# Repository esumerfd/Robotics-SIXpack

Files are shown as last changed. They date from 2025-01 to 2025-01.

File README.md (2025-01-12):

# Robotics-SIXpack

A free Robotics hexapod by delta3robotics. 

* https://wonderl.ink/@delta3robotics
* https://cults3d.com/de/modell-3d/verschiedene/sixpack

Chris wrote all the original code and hosts a Discord to help people learn about robotics.

* https://discord.com/invite/fj6HPAsYT8

I am a novice in robotics so these are just my experiments built on top of Chris's work.

My goal is to add a build and upload solution that doesn't use the Arduino IDE. So, a 
simple `make` solution using the arduino-cli to build and upload.

# Install - Mac only.

* brew install arduino-cli
* USB to Serial
    * Macs older than Maverics need these drivers, but new are good to go.
        * Install FTDI drivers: https://ftdichip.com
* make init

# Build

The build step installs the packages and runs the arduino-cli compile to generate the image

* make build

# Upload

You will have to work out the serial port to upload to. Once you have plugged it in, you should see it in this list

* make usb

Then you can upload the built solution:

* SERIAL_PORT=/dev/cu.usbserial-OR-SOMETHING make upload

# Debugging

Trying to create an independent module that can be used to verify the hardware is functioning as expected. A website contains options to testing each component.

* make PROJECT=Firmware/SIXpackDebug build

# References

RS-232 comms. The communication between the computer and the esp32-cam requires a usb to serial connection that is achieved with a device driver and a chip of some kind. A common solution is the FTDI FT232RL chip mounted on a board. You can get a couple from Amazon:

* [Amazon FTDI component](https://www.amazon.com/gp/product/B07WYLK437)

If you are interested in the backround of RS-232 and how it works at the link level this is a good article.

* [MacOS Big Sur & RS-232 Serial Communications](https://just.graphica.com.au/tips/macos-big-sur-rs232/)

Ultimatly you don't need any additional serial drivers since Mac OSX includes its own in versions 11 onwards. I am testing on Serquoia 15 and it works.

Optional alternative USB -> Serial driver:

* [Prolific PL2303GT](https://www.prolific.com.tw/us/ShowProduct.aspx?pcid=41&showlevel=0017-0037-0041)
* [Aideepen USB to TTL RS232 3.3V Serial Download Cable Adapter Original 6PIN 5V FTDI-232 Module 1M Wire AVR ARM(Combined Head)](https://www.amazon.com/gp/product/B07FVMCPMT)
* [HiLetgo 5pcs USB to Serial USB to TTL CH340 Module with STC Microcontroller Download Adapter](amazon.com/gp/product/B00LZV1G6K)
* [PL2303GT USB to RS232 Serial Cable - UART Upgrade Download Module for RS232 Level (Non-TTL)](https://www.amazon.com/dp/B0D3CFX4PC)

## Mac FTDI Story

When I first started this project everything work, the ftdi drivers installed and everything worked. Then I got a new mac i9 chip, running OSX 15, and nothing worted anymore.

In the old days, and based on Chris's instructions, an FDTI chip set is required to connect to the esp32cam board. 

Today, the FTDI board, has build in support in Mac OSX for this board.

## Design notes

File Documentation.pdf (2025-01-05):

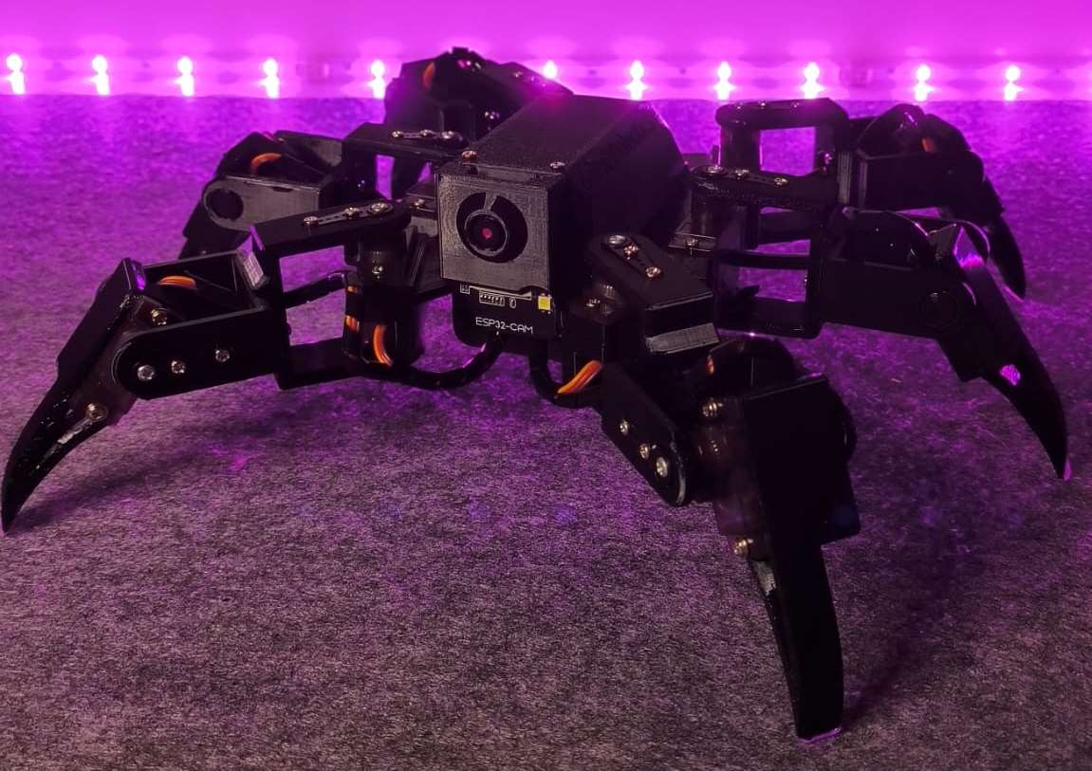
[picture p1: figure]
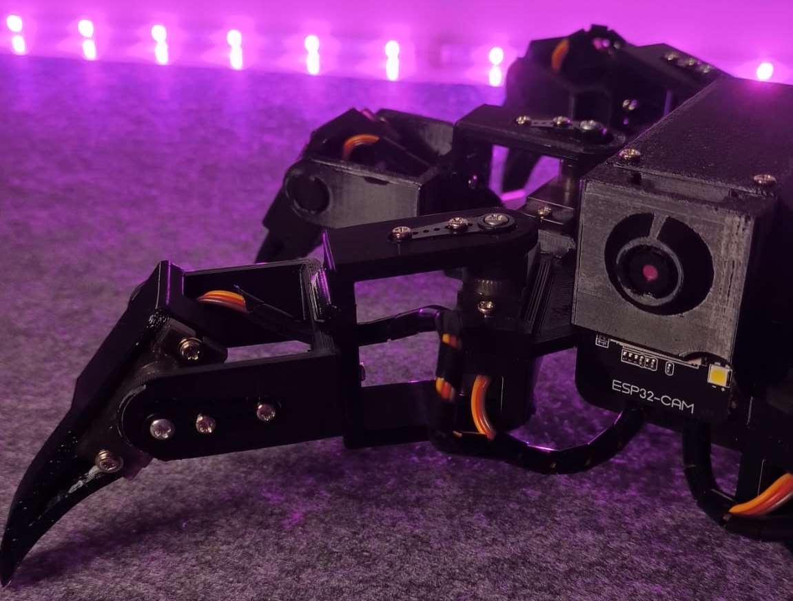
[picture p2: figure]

delta3Robotics | SIXpack documentation | IV

# delta3Robotics

## SIXpack

Documentation

delta3Robotics | SIXpack documentation | V

Table of Contents

### 1 Introduction | VI

### 2. Assembly instruction | VII

### 2.1 What to Buy | VII

### 2.2 Printing | IX

### 2.3 Assembly | XI

### 2.3.2 Wireing | XIV

### 2.3.3 Location for Servos on PCA9685 | XVI

### 2.3.4 Calibration | XVII

### 2.4 Connect a client to the access point | XIX

### 3. Trouble Shooting | XX

### 3.1 Shaking / jittering servo motors | XX

### 3.1.1 Lower the legs to have contact in idle position | XX

### 3.1.2 Increase the friction inside the affected links | XX

### 3.2 Flipped camera feed | XXI

### 3.3 Servos are not working | XXI

### 3.3.1 Wiring made incorrect | XXI

### 3.3.2 Insufficient Power supply | XXII

### 3.3.3 Broken PCA Board | XXII

### 3.4 Buttons are not working | XXII

### 3.5 Slippery feet | XXIII

### 4. Acknowledgements | XXIII

### 4.1 Muxiddin | XXIII

delta3Robotics | SIXpack documentation | VI

### 1 Introduction

SIXpack is a project dedicated for people that want to start Robotics and Engineering. The robot is fully 3D-printed, and everything is published for free.

To steer the robot, you need a Tablet with any browser installed. Ther ESP32cam sets up an access point after powering it up. After connecting the user interface and camera feed is shown.

If you get stuck somewhere you can ask me, write a DM on Instagram @delta3Robotics or send an email to chris@delta3robotics.de

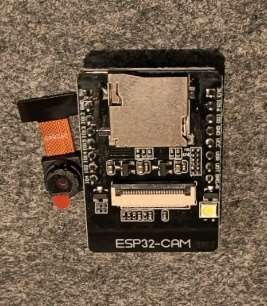
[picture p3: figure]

delta3Robotics | SIXpack documentation | VII

### 2. Assembly instruction

This chapter will guide you step for step trough the building process. In general, building this robot takes between 3-4 Hours, don’t get frustrated if your first attempt takes longer.

### 2.1 What to Buy

Not all parts can be printed, therefore please refer to the List below and buy the parts at any source you like.

Full amazon list: https://amzn.to/3wQY4Tq

| Titel | Note | Amazon link
1x | ESP32cam | | https://amzn.to/48imAdp
12x | Servomotors | The design should fit every kind of MG90s or MF90 and SG90 | https://amzn.to/3wpSuHu
1x | PCA9685 | | https://amzn.to/48dSzeM
1x | Battery holder | Battery holder for two 18650 LiPo batteries LxW 76x40mm | https://amzn.to/3T2CLqZ

delta3Robotics | SIXpack documentation | VIII
2x | 18650 Batteries | Get some of AMAZON or check Craigslist for used ones. Any 18650 can power the robot. | https://amzn.to/3I30PU6

Bits and bolds

| Socket header | Two times with 8 Sockets or get the larger ones and cut them | https://amzn.to/3UHVklf
| Screws | Pan Head self-tapping Screws M2*4 and M2*8 | https://amzn.to/49hOEyN
| Jumper wires | Only must have is that one side is the female part | https://amzn.to/3TacOpz
1x | Switches | Sliding button three position 2P2T DPDT SS23D32 F3E4 | https://amzn.to/3OIg1tu
1x | FDTI Adapter | Check that the USP port of the adapter fits any cable you have to connect it to the computer | https://amzn.to/49CoDKs
1x | Charger | | https://amzn.to/49woMy M

delta3Robotics | SIXpack documentation | IX

Cable
Conduit

https://amzn.to/4bDlKuE

If you can wait Aliexpress normally got the pest prices. I included some amazon links you can use. You will pay more than on Aliexpress! But you have the hardware I used for testing, and I get some bucks f you buy there!

You can start out using cheap SG90 servos. If you like you can upgrade, it later.

There is an affordable a plug and play alternative for the FTDI chip you can use, since I don’t have any experience with that device, I will refer to the good old FTDI chip in this document.

### 2.2 Printing

This chapter describes the process on how to print all the parts you need. Feel free to differ from this manual if you feel confident. Here I will list some settings that worked for me.

1x | Head
1x | Body
3x | CapRight
3x | CapLeft
1x | BodyLid
12x | LegUPart
3x | LegOuterPart
3x | LegOuterPart | mirrored

Here you can see hoe to orientate the Parts for the print. I use my Prusa mini and split everything into 4 Prints. There is one print for Body, Lid, Head and the six Caps. Another

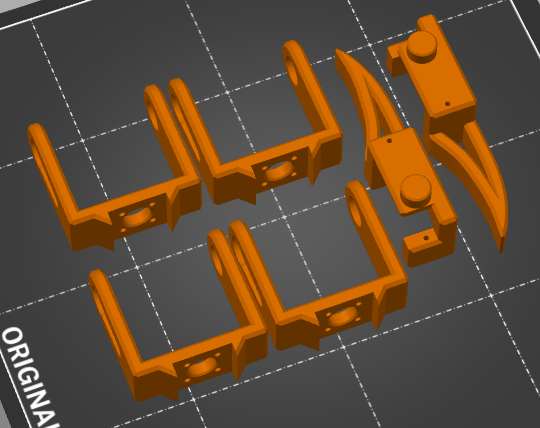
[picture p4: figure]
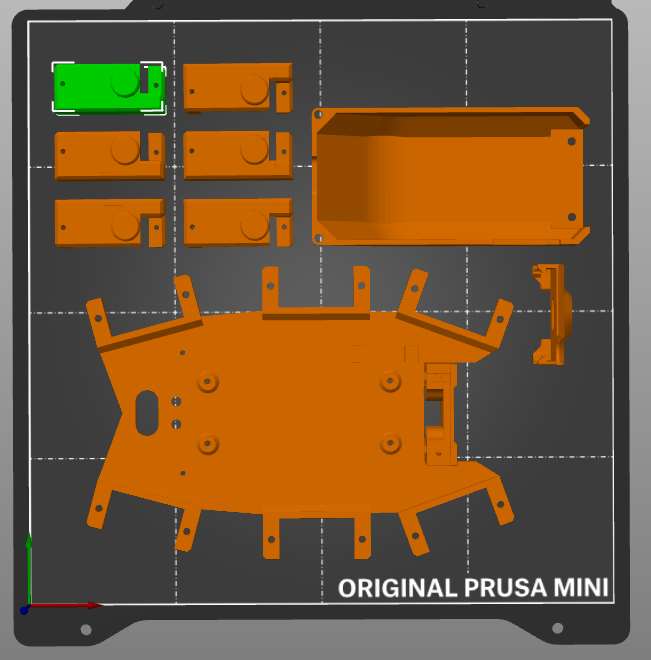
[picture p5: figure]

delta3Robotics | SIXpack documentation | X

print holds two legs each with LegOuterPart, LegOuterPart (mirrored) and four times LegUPart. This print is done three times to get 6 legs.

Figur 1 Print orientation for two legs

Figur 2 Build orientation for the remaining body parts
Support Structure is definetly needed. Print at least four parameters to have a rigid and durable part.

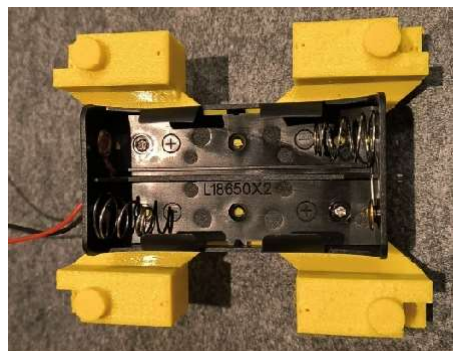
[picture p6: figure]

delta3Robotics | SIXpack documentation | XI

### 2.3 Assembly

Now we take care for the mechanical assemly.

### 2.3.1 Mechanical Assembly

Most things are pretty similar to ESPiderman. Please don’t get confused that a lot of pictures show another robot.

First mount the batteriy box unter the body. The cables must be at the front. Under the neck section is space to guide them into the robot. Take two M2x4 srews and use the dedicated holes. If your batteriy box differs in layout try to screw it directly into the plastic.

Figur 3Body with battery box
Then take the socket header and cut it to length. You will need two of them. Ther is the option to buy two times 1x8 socket header but if yu buy the log ones and cut them, you’ll end up cheaper. After you cut it to length tae a file and remove the access material. Important is, the socket headers that are pushed into the body to take up the ESP32cam afterward must be sled in very carefully. If the pushing needs to much effort try to work on the slots, otherwise the bodypart might breake. After pushing them in completely secure them with two M2*4 each.

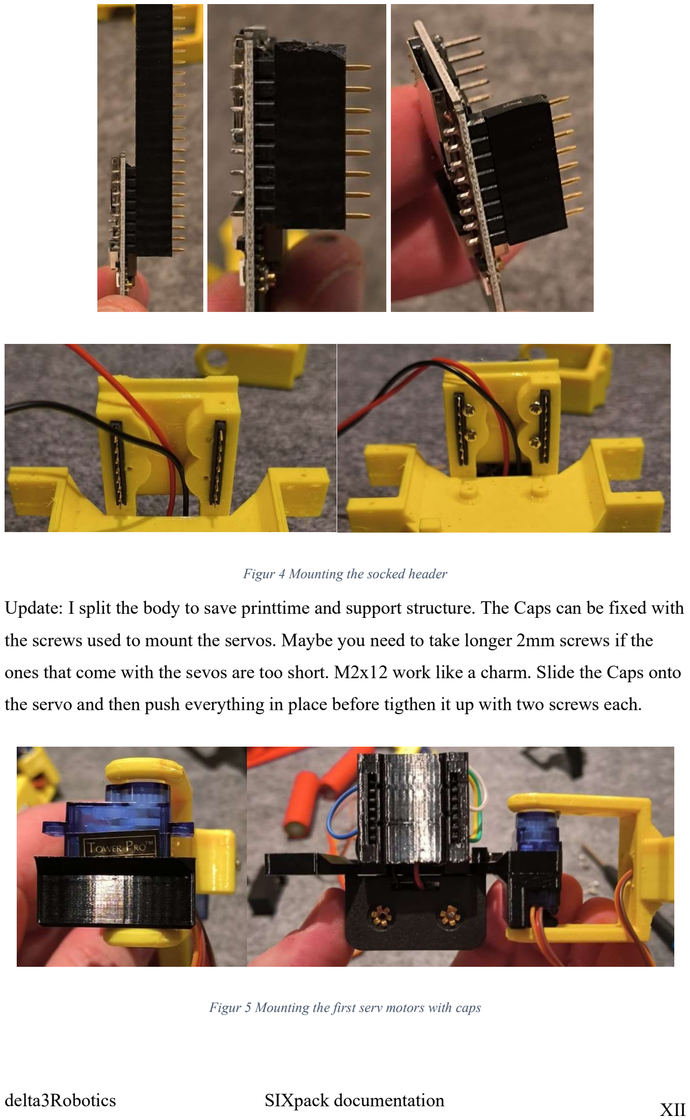
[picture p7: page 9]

delta3Robotics | SIXpack documentation | XII

Figur 4 Mounting the socked header
Update: I split the body to save printtime and support structure. The Caps can be fixed with the screws used to mount the servos. Maybe you need to take longer 2mm screws if the ones that come with the sevos are too short. M2x12 work like a charm. Slide the Caps onto the servo and then push everything in place before tigthen it up with two screws each.

Figur 5 Mounting the first serv motors with caps

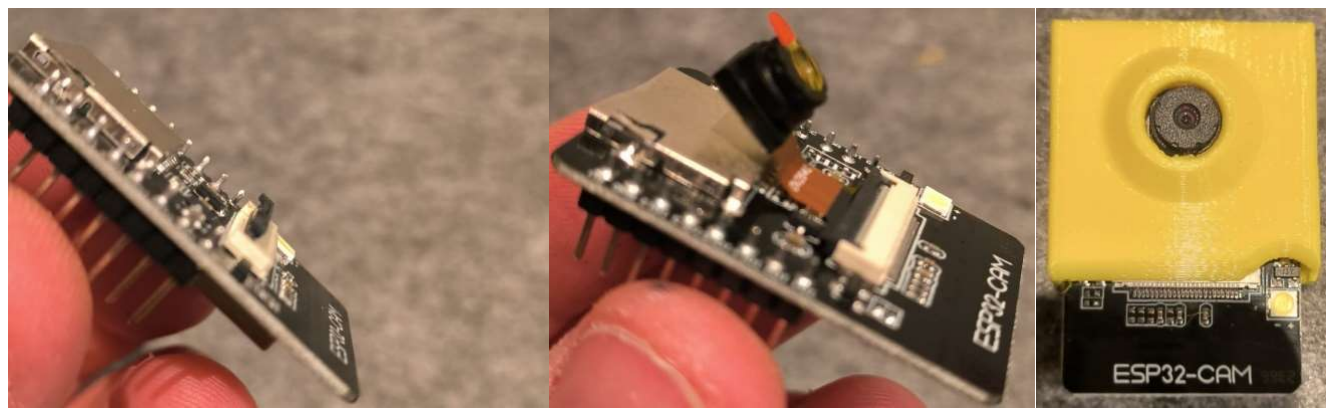
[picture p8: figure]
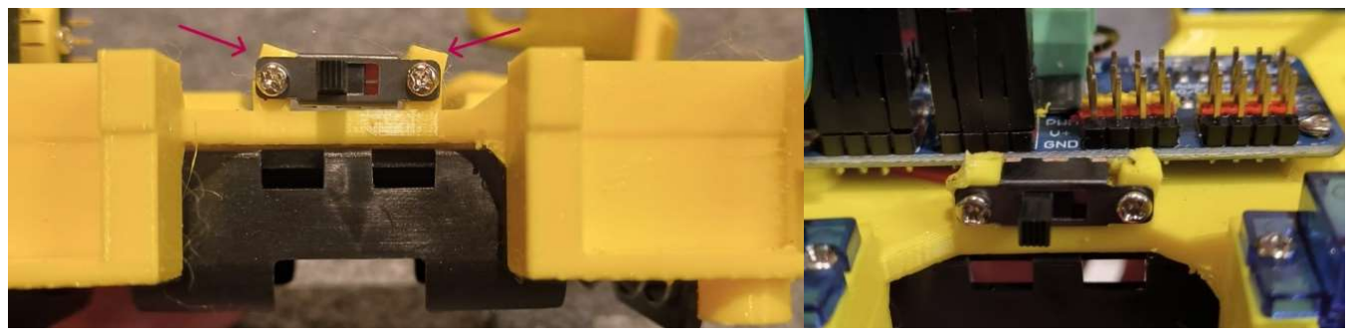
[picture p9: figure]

delta3Robotics | SIXpack documentation | XIII

Now we can assemble the ESP32cam. Open the flap by pulling up the lid. Slide in the camera module all the way and close the flap again. The printed part for the head can be gently pushed onto the ESP. Therfore, push it all the way up and then click it onto the controller. The ESP can be put in place now. Gently slide all 8 pins into the socket header.

Now take the swith and screw it into place. The mouning is super fragile and might brack if you are not careful enough. Gently fix the swith with 2 M2x4 screws. If the mount is damaged like senn in the pictures below one can use a soldering iron to repair it.

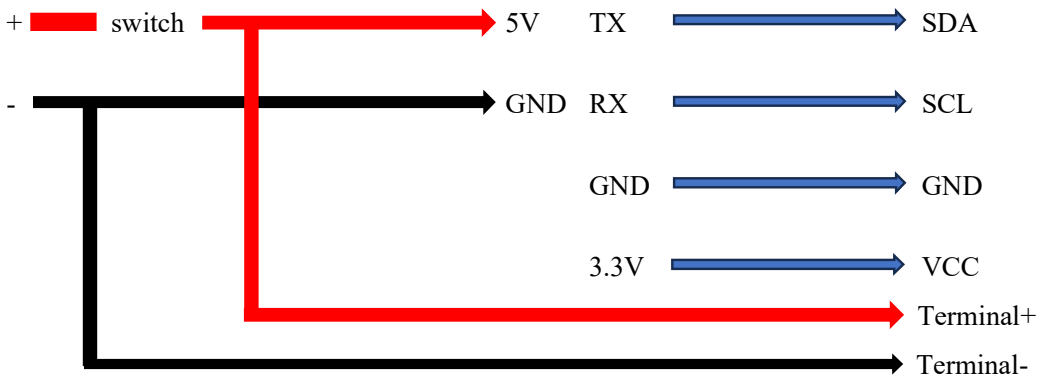
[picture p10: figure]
switch; SDA; GND RX; SCL; GND; VCC; Terminal+; Terminal-
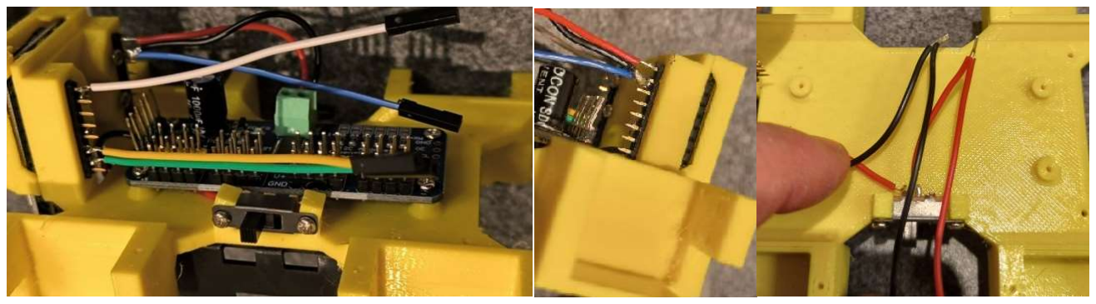
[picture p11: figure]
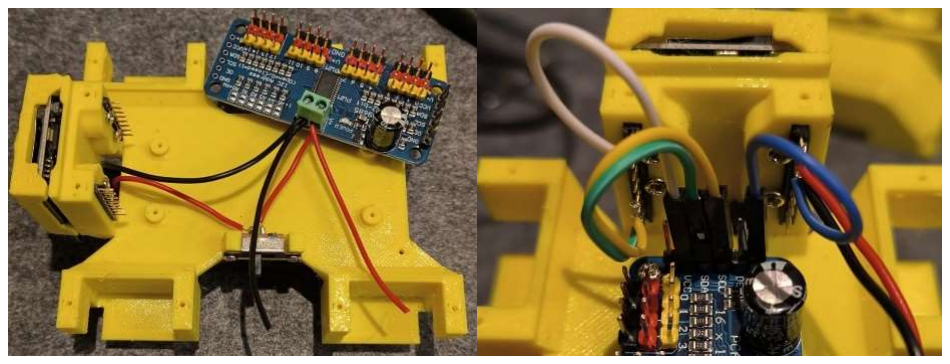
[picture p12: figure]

delta3Robotics | SIXpack documentation | XIV

### 2.3.2 Wireing

I get a lot of questions about the voltage level for the ESP and PCA. 7.4 Volts is not too much for the devices. The internal power management supports up to 15V on both chips. For the ESP that holds true for the 5v pin and for the PCA it is the terminals, the logic side does not support that much current, take the 3.3 V output pin from the ESP.

Batterie holder | ESP32cam | PCA9685

All the connections on the socket header need to be soldered. The connections on the PCA can be plugged with jumper ends, but to do so the Pins on the PCA must be bend upwards, if the pins are the ones with a 90° angle.

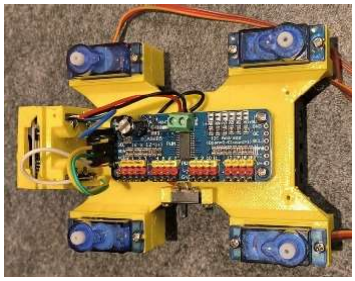
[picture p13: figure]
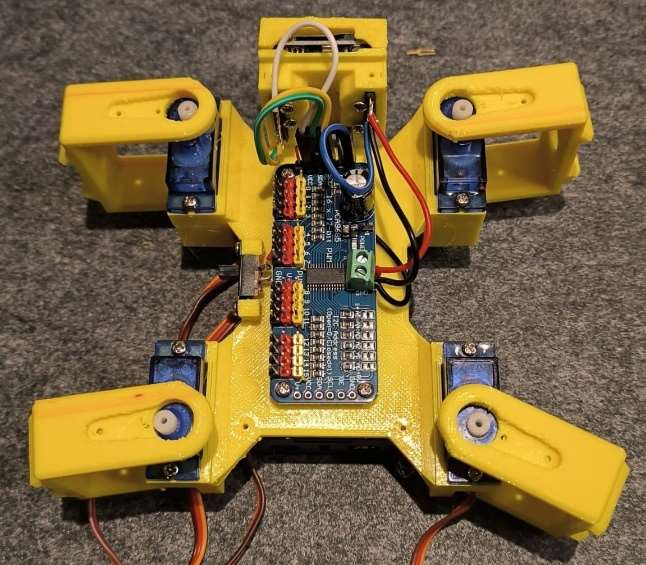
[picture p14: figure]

delta3Robotics | SIXpack documentation | XV

Fix the PCA9685 with 4 M2x4 screwys and connect the jumperwires according to the schematic.

Mount the first servos like shown in the foto. The middel legs are ptretty much the same like the rear legs. Don’t hate me for beeing lazy please.

Put on the first LegUPart per servo. Do not attach the servo horns for now.

Now Put on another LegUpart per leg. Make sure that the spot for the servo horn points to the Front for the front legs and backwards for the back legs. Fix each connection with 4 M2x12 screw.

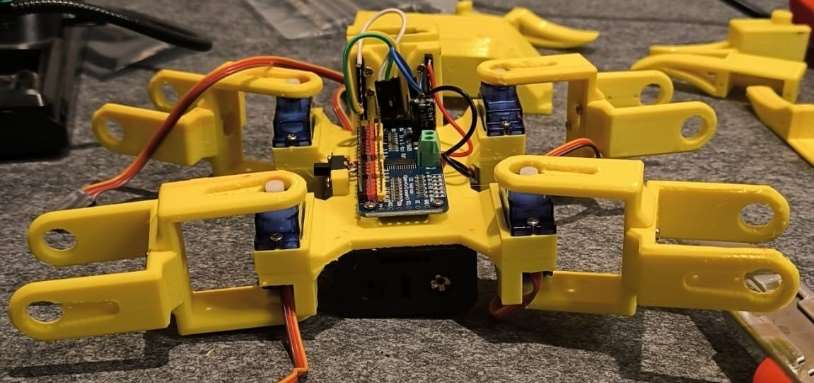
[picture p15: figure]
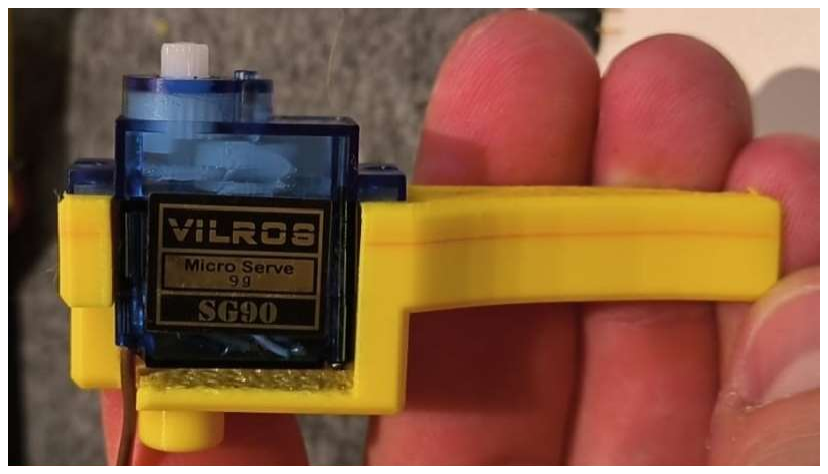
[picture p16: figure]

delta3Robotics | SIXpack documentation | XVI

Now slide one servo into each LegOuterPart and fix it with screws.

Mount the four remaining parts to the legs.

### 2.3.3 Location for Servos on PCA9685

Logical counting start at 0. The first servo is 0 and the port on the PCA for servo 0 is called 0, too.

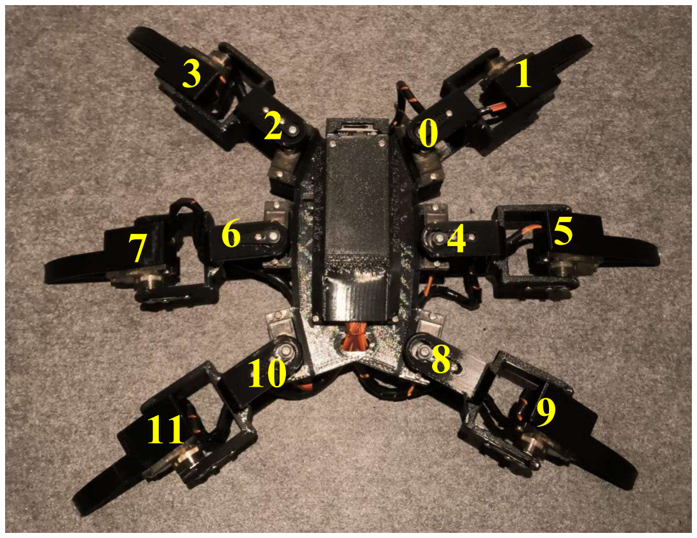
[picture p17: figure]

delta3Robotics | SIXpack documentation | XVII

After everything is connected, screw the lid on top to hide all the nasty cable connections. Before you screw the lid on fully, make sure that there is enough cable length for the legs to be fully operated.

### 2.3.4 Calibration

First thing to do is to set the servos on neutral (90°), I personally like to use a servo tester, a cheap device. If you do not have one, here is what to do! If we upload the code as it is the robot will start in its idle position which is not the one, we need!

We do not want it to be like that, so open the code and set legIdle = korr = 0

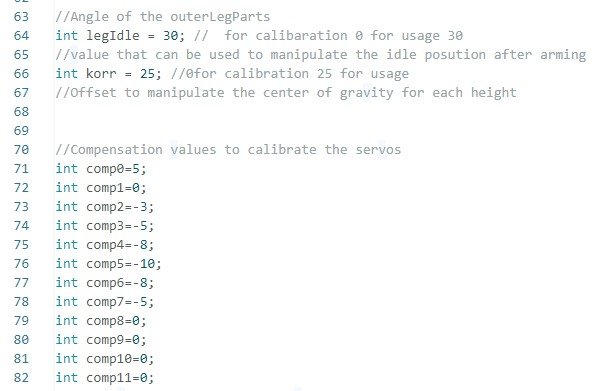
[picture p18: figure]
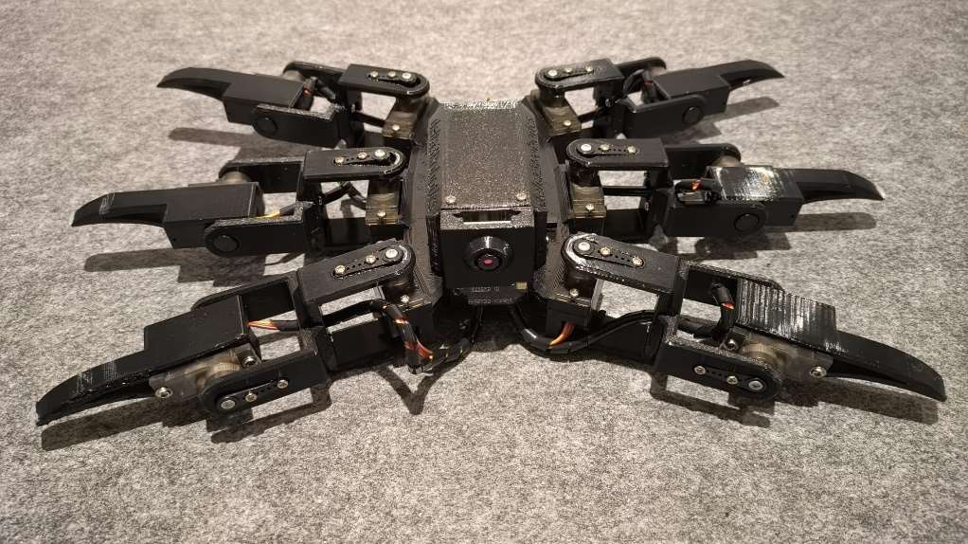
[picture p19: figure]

delta3Robotics | SIXpack documentation | XVIII

Figur 6 orig snippet from my code
Further make sure that all the compensation values (comp0-comp11) are set to zero.

2.3.4.1 Upload the code.

The internet is full on how to download the Arduino IDE and how to connect the ESP32cam to the computer to upload code! Therefor I will not explain it further. If you never programmed an ESP32cam I would suggest doing some testing with the Webserver example sketch you can find after integrating all the stuff you need to program ESP32cam with the Arduino IDE. It is not easy to do for the first time, but you can do that!
As soon as you are done with your testing, and you are confident enough open the adapted code and upload it to the controller. Put the controller into the socket header and power the robot on. The controller sets all servos to 90°, that is exactly what we want to mount the servo horns. Put the links into the correct position and mount the horns, after mounting all the horns the robot should look like this.

Figur 7 Robot pose for calibaration

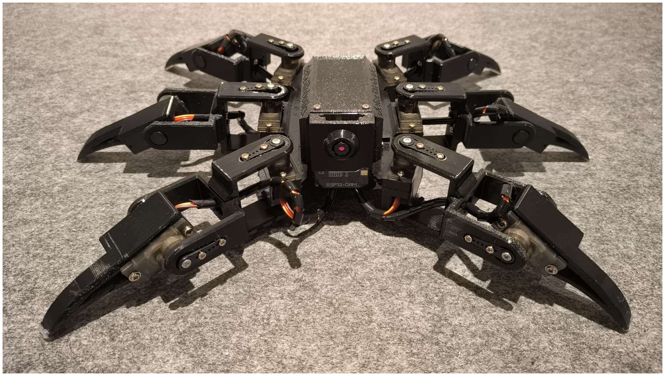
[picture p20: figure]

delta3Robotics | SIXpack documentation | XIX

This will not be in a perfect 90° angle, do the best you can, the rest will be done in code. For this we must play a bit with the values comp0-comp11. Take your time and find values to drive the servos exactly to 90°. For this adapt values, I would recommend changing one value at the time, upload, power on the robot and check if the link is set to 90°.

As soon as you are satisfied with your calibration, set korr and legIdel back to the values mentioned in the comment next to each value and upload it again. The robot should look this now.

Figur 8Robot idle position

Congratulations! Your robot should be calibrated now.

2.4 Connect a client to the access point.

To connect a client to your webserver which is running on the ESP, power on your bot. After some seconds Take a Tablet (right now only touchscreen devices are supported, and I would highly suggest taking a tablet, otherwise the buttons are way to small :/ ) and connect to the Wi-Fi “SIXpack” the password is “delta3robotics”. Btw you can change that easily in the code.

delta3Robotics | SIXpack documentation | XX

After the connection is established, there will come a warning since your device can not connect to the internet. Little side tip, if your device switches automatically to other Wi-Fi networks due to quality of connection it will switch out of “SIXpack” so turn that setting off, I cannot do it in the code. Now you can enter the following IP-address to any browser: 192.168.4.1 and maybe hit the refresh button. Safe the tab as favorite so you do not have to input the IP every time.

If there are any questions left feel free to send me a DM, @delta3Robotics on Instagram is my main channel!

And that is it! You built your own robot! I am proud of you!

### 3. Trouble Shooting

### 3.1 Shaking / jittering servo motors

Due to bad resolution and backlash, cheap servos tend to jitter if no load is applied. This will most likely happen with SG90 but can also affect more expensive servo types. Ther are two solutions that may work.

### 3.1.1 Lower the legs to have contact in idle position

This solution is implemented in the code you have. By setting the legs to legIdle the feet should have contact with the ground. If this is not the case, you have to increase this value a bit to stop it from shaking.

### 3.1.2 Increase the friction inside the affected links

You can take a piece of cloth or sponge and put it inside the link. Like this you increase the friction, and the backlash will not resonate, so the jittering stops.

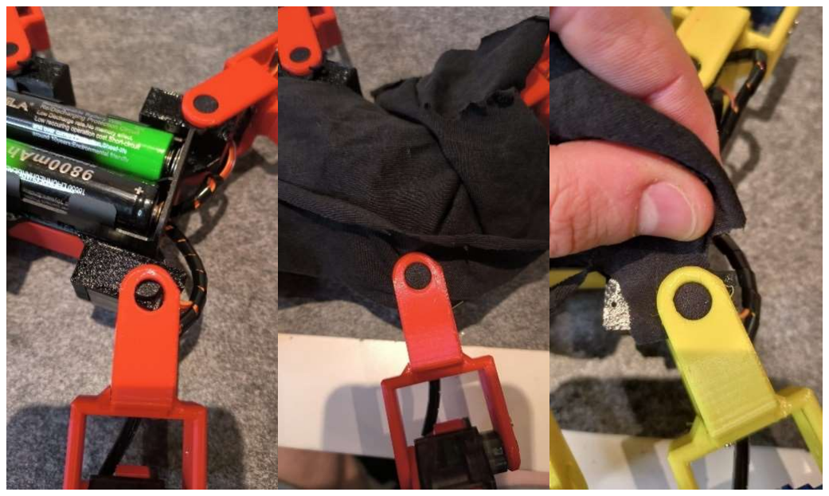
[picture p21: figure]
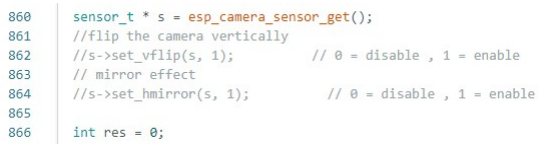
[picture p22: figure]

delta3Robotics | SIXpack documentation | XXI

### 3.2 Flipped camera feed

Some camera modules seem to be flipped. From the outside you cannot see it but the camera feed at the webserver is flipped upside down. To change that you can use inbuilt functions in the code.

By uncommenting the corresponding line, you can flip and/or mirror the camera feed.

### 3.3 Servos are not working

The robot is fully assembled but the motors are not driven? Sadly, this can have several issues.

### 3.3.1 Wiring made incorrect

Please double check that the RX/TX/SDA/SCL are connected like described in Section

### 2.3.2 Wireing. If the SDA and SCL lines are crossed ther will be no communication

between PCA and ESP. Make sure that works.

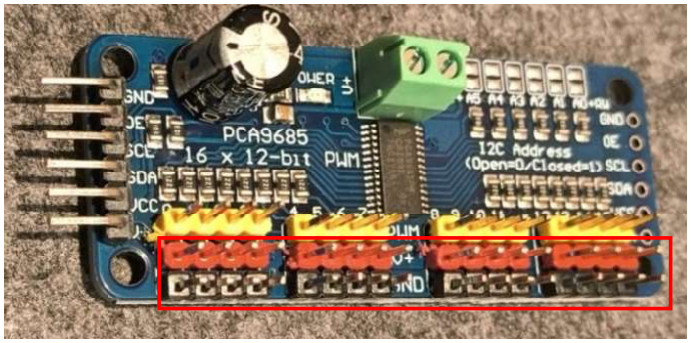
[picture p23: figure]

delta3Robotics | SIXpack documentation | XXII

### 3.3.2 Insufficient Power supply

Charge the batteries! One servo can pull 400mA peak. That means if all servos are actuated the robot needs more that 3.2 A peak! The 18650 can do so, but only if charged fully. A good sign to charge the batteries is if it worked before or everything works fine until the servos should start working.

### 3.3.3 Broken PCA Board

Check that the Voltage between the V+ and GND pins on the PCA. For that you need a Multimeter. Power on the robot and measure at any red and black pin.

Most PCA9685 boards have a transistor that blocks the voltage if the logic part of the PCA is not active. Sadly, a lot of board out there exactly this transistor is broken. If the robot is powered on but there is no voltage > 7.4 V at the indicated pins your board is most likely broken, and you must replace it.

### 3.4 Buttons are not working

You powered up the robot and connected to the webserver, but the robot does not respond? Check if the flashlight is working. If the flashlight is working, there is a problem with the I2C connection. Why? Because the flashlight is the only device that is integrated directly into the ESP, everything else is send from the microcontroller to the PCA board.

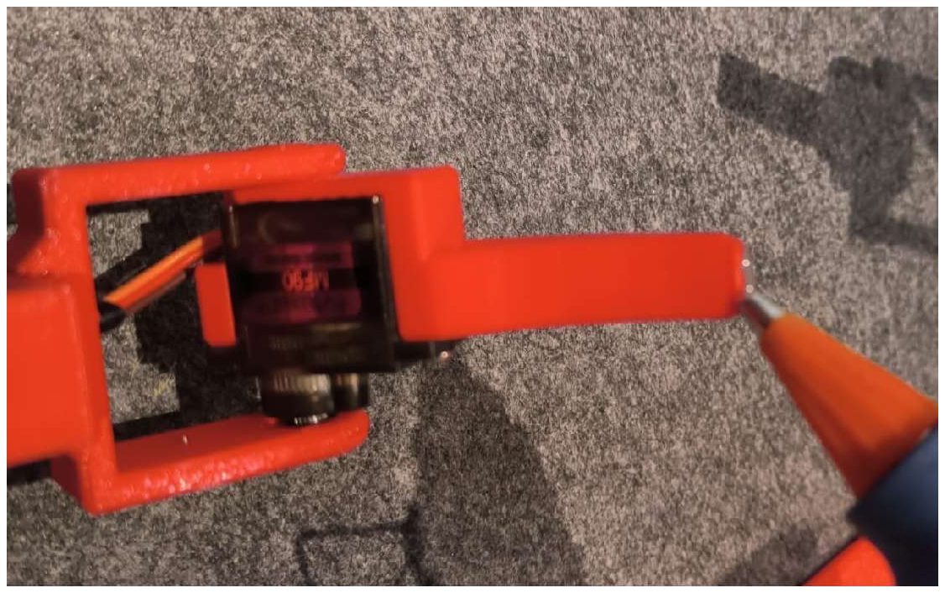
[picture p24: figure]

delta3Robotics | SIXpack documentation | XXIII

If the flashlight does not work as well, you most likely use the wrong device to control the robot. Right now, the buttons only work with touch devices. This is on my issue list but with a very low priority.

### 3.5 Slippery feet

You’ll notice that the feet are slippery. To increase the friction and reduce slipping you can apply hot glue onto the tips of the feet.

### 4. Acknowledgements

This section shall be used to thank people that put in work and shared their findings. Like this, we all can make this project great.

### 4.1 Muxiddin

MF is one of the first Instagram user to join this project. The robot was printed and assembled very fast. Parts were modified to fit other components like bigger switches and an ESP with a bigger camera. Also Muxiddin came up with the solution to insert pieces of sponges into the links and therfore decreasing the jittering of servo hysteresis.

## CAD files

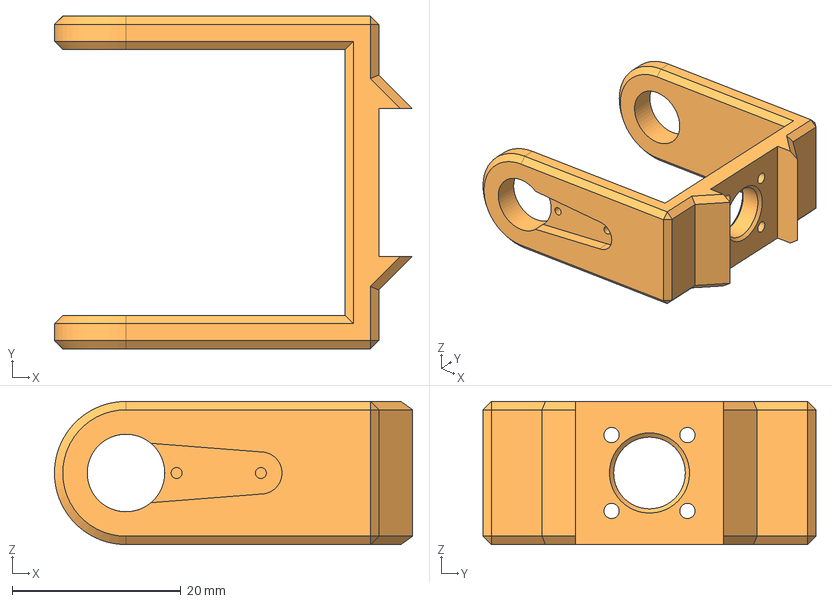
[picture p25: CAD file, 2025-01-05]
STEP/LegUPart.step
42.5 x 39.5 x 17.0 mm

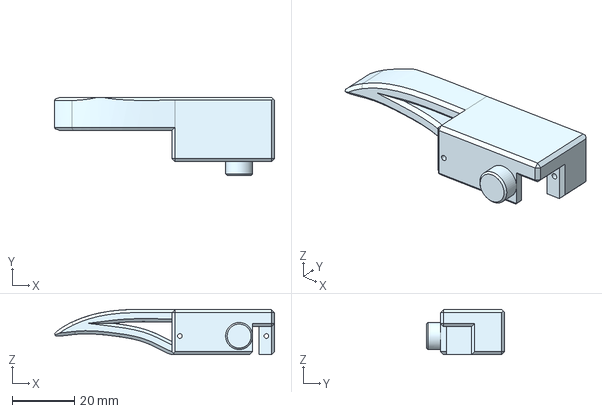
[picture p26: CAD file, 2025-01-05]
STEP/LegOuterPart.step
70.7 x 25.2 x 14.6 mm

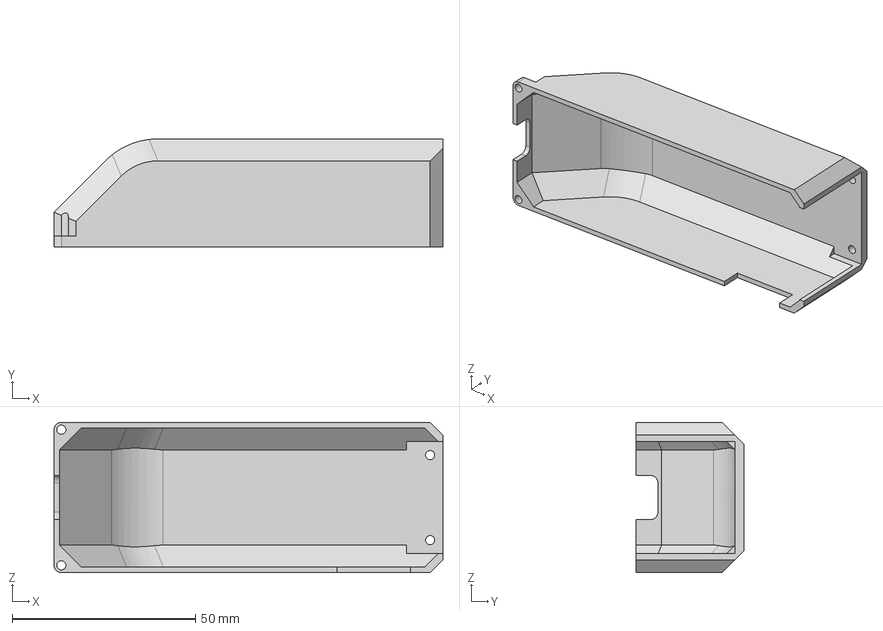
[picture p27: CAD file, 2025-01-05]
STEP/Lid.step
106.1 x 29.5 x 41.0 mm

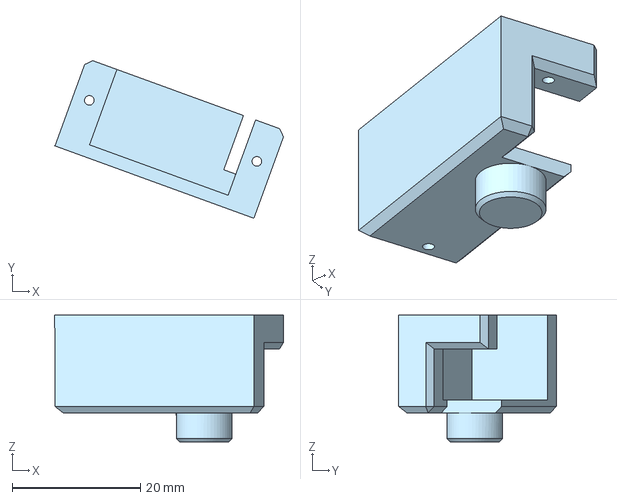
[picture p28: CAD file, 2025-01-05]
STEP/CapLeft.step
35.7 x 24.6 x 19.7 mm

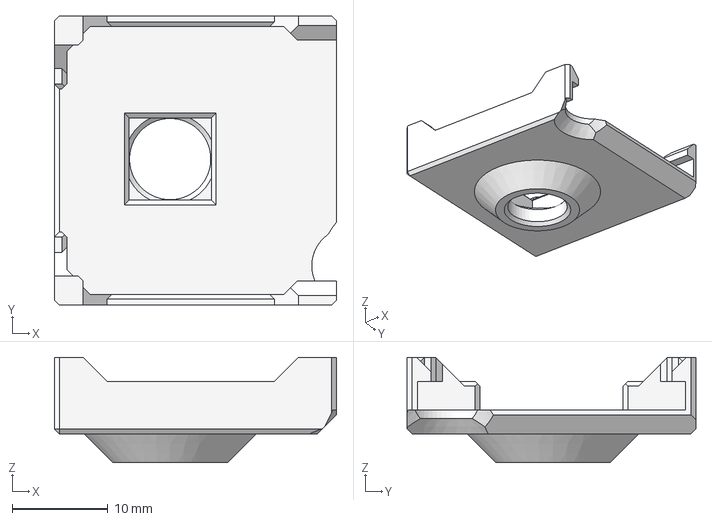
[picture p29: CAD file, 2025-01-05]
STEP/Head.step
29.5 x 30.2 x 11.0 mm

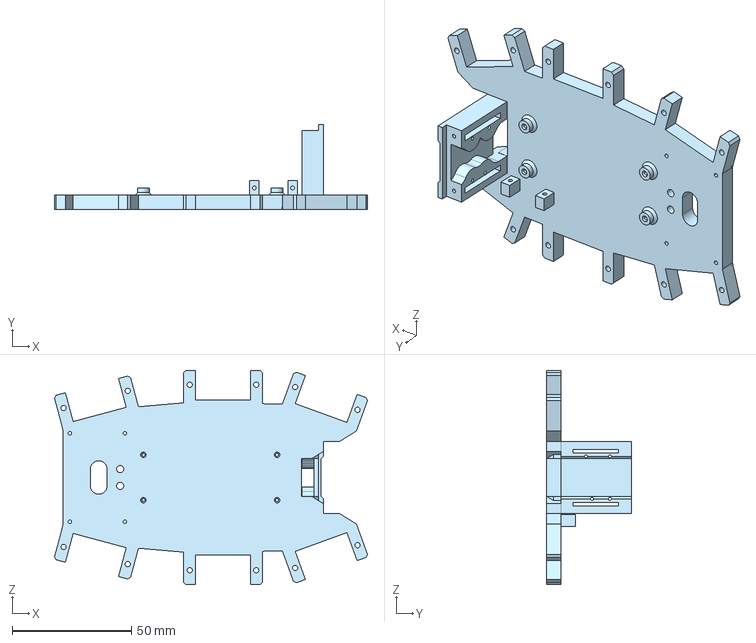
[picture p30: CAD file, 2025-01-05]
STEP/Body.step
131.0 x 35.5 x 89.7 mm

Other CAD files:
STEP/CapRight.step
STL/Body.stl
STL/CapLeft.stl
STL/CapRight.stl
STL/Head.stl
STL/LegOuterPart.stl
STL/LegUPart.stl
STL/Lid.stl

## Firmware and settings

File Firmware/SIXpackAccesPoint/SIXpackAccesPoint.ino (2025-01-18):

#include "esp_camera.h"
#include <WiFi.h>
#include "esp_timer.h"
#include "img_converters.h"
#include "Arduino.h"
#include "fb_gfx.h"
#include "soc/soc.h"             // disable brownout problems
#include "soc/rtc_cntl_reg.h"    // disable brownout problems
#include "esp_http_server.h"
#include <Wire.h>
#include <Adafruit_PWMServoDriver.h>

// Credential for the Wifi access point
//feel free to change that
const char* ssid = "SIXpackOrig";
const char* password = "aaaaaaaa";
//Instatntiation of communication variables, this was made for Alpha 
//most of them are not used for ESPiderman and can be deleted carefully
bool lightOn=false;
bool lightStrobe=false;
bool strobeOn=false;
bool arm=false;
bool wave=false;
int ch_1=1500;
int ch_2=1500;
int ch_3=1500;
int ch_4=1500;
int ch_5=1000;
int ch_6=1000;
int ch_7=1000;
int ch_7_old=1500;
int ch_8=1000;
int ch_9=0; 
//Instantiation of feedback variables, same as for the communication variables
char dataToClient[70];
String feedBackToClient;
String light="1000";
String armed="1000";
String height="1000";
String mode="1000";
String footFL="1000";
String footFR="1000";
String footBL="1000";
String footBR="1000";
String temp=" ";
String rotX=" ";
String rotY=" ";
String rotZ=" ";
String distFr=" ";
String distFrL=" ";
String distFrR=" ";
String distBott=" ";

//Tell the program which pins shall be used for the I2C communication
#define i2c_sda 1
#define i2c_scl 3

//Instantiation of varables used for ESPiderman walking gaits
Adafruit_PWMServoDriver pwm = Adafruit_PWMServoDriver();
//a0-a7= target angles, a0r-a7r= current angles
int a0, a1, a2, a3, a4, a5, a6, a7, a8, a9, a10, a11, a0r, a1r, a2r, a3r, a4r, a5r, a6r, a7r, a8r, a9r, a10r, a11r; 

//Angle of the outerLegParts
int legIdle = 30; //  for calibaration 0 for usage 30
//value that can be used to manipulate the idle posution after arming
int korr = 25; //0for calibration 25 for usage
//Offset to manipulate the center of gravity for each height


//Compensation values to calibrate the servos
int comp0=5;
int comp1=0;
int comp2=-3;
int comp3=-5;
int comp4=-8;
int comp5=-10;
int comp6=-8;
int comp7=-5;
int comp8=0;
int comp9=0;
int comp10=0;
int comp11=0;
//negative fullscale and positive fullscale,  this is used to tell the PCA9685 at which pulse 
//a servo is set to 0° and at which to 180°, maybe you need to change the values if other servosw
//are used
int pos0 = 150;
int pos180 = 650;
//Delay to decrease the Speed. This is in milli seconds so almost zero, if you want to speed up the gaits
//you have to do it at the ramped controller at the end
int v = 3;
int vFast = 3;
//Different speed for locomotion
int vSlow = 30;
//degrees that are set in each iteration of the controller
int t = 4;
//deadband that is drawn around stall position of servo to avoid jittering servos
int eps = t+3; 

//Delay for liftLeg() and lowerLeg() functions, is used to wait until the movement is done
int y = 75;
//counter for steps in each movement sequenz
int step = 0;

//height and width of a step, this is set for every heigt seperate
int stepLift = 0;
int stepLiftLow = 35;
int stepLiftMid = 40;
int stepLiftHigh = 45;

int stepLength = 0;
int stepLengthLow = 40; 
int stepLengthMid = 40; 
int stepLengthHigh = 40;    


//Section to define different cameramodels and chip types
#define PART_BOUNDARY "123456789000000000000987654321"
#define LED_BUILTIN 4
#define CAMERA_MODEL_AI_THINKER
//#define CAMERA_MODEL_M5STACK_PSRAM
//#define CAMERA_MODEL_M5STACK_WITHOUT_PSRAM
//#define CAMERA_MODEL_M5STACK_PSRAM_B
//#define CAMERA_MODEL_WROVER_KIT

#if defined(CAMERA_MODEL_WROVER_KIT)
  #define PWDN_GPIO_NUM    -1
  #define RESET_GPIO_NUM   -1
  #define XCLK_GPIO_NUM    21
  #define SIOD_GPIO_NUM    26
  #define SIOC_GPIO_NUM    27
  
  #define Y9_GPIO_NUM      35
  #define Y8_GPIO_NUM      34
  #define Y7_GPIO_NUM      39
  #define Y6_GPIO_NUM      36
  #define Y5_GPIO_NUM      19
  #define Y4_GPIO_NUM      18
  #define Y3_GPIO_NUM       5
  #define Y2_GPIO_NUM       4
  #define VSYNC_GPIO_NUM   25
  #define HREF_GPIO_NUM    23
  #define PCLK_GPIO_NUM    22

#elif defined(CAMERA_MODEL_M5STACK_PSRAM)
  #define PWDN_GPIO_NUM     -1
  #define RESET_GPIO_NUM    15
  #define XCLK_GPIO_NUM     27
  #define SIOD_GPIO_NUM     25
  #define SIOC_GPIO_NUM     23
  
  #define Y9_GPIO_NUM       19
  #define Y8_GPIO_NUM       36
  #define Y7_GPIO_NUM       18
  #define Y6_GPIO_NUM       39
  #define Y5_GPIO_NUM        5
  #define Y4_GPIO_NUM       34
  #define Y3_GPIO_NUM       35
  #define Y2_GPIO_NUM       32
  #define VSYNC_GPIO_NUM    22
  #define HREF_GPIO_NUM     26
  #define PCLK_GPIO_NUM     21

#elif defined(CAMERA_MODEL_M5STACK_WITHOUT_PSRAM)
  #define PWDN_GPIO_NUM     -1
  #define RESET_GPIO_NUM    15
  #define XCLK_GPIO_NUM     27
  #define SIOD_GPIO_NUM     25
  #define SIOC_GPIO_NUM     23
  
  #define Y9_GPIO_NUM       19
  #define Y8_GPIO_NUM       36
  #define Y7_GPIO_NUM       18
  #define Y6_GPIO_NUM       39
  #define Y5_GPIO_NUM        5
  #define Y4_GPIO_NUM       34
  #define Y3_GPIO_NUM       35
  #define Y2_GPIO_NUM       17
  #define VSYNC_GPIO_NUM    22
  #define HREF_GPIO_NUM     26
  #define PCLK_GPIO_NUM     21

#elif defined(CAMERA_MODEL_AI_THINKER)
  #define PWDN_GPIO_NUM     32
  #define RESET_GPIO_NUM    -1
  #define XCLK_GPIO_NUM      0
  #define SIOD_GPIO_NUM     26
  #define SIOC_GPIO_NUM     27
  
  #define Y9_GPIO_NUM       35
  #define Y8_GPIO_NUM       34
  #define Y7_GPIO_NUM       39
  #define Y6_GPIO_NUM       36
  #define Y5_GPIO_NUM       21
  #define Y4_GPIO_NUM       19
  #define Y3_GPIO_NUM       18
  #define Y2_GPIO_NUM        5
  #define VSYNC_GPIO_NUM    25
  #define HREF_GPIO_NUM     23
  #define PCLK_GPIO_NUM     22

#elif defined(CAMERA_MODEL_M5STACK_PSRAM_B)
  #define PWDN_GPIO_NUM     -1
  #define RESET_GPIO_NUM    15
  #define XCLK_GPIO_NUM     27
  #define SIOD_GPIO_NUM     22
  #define SIOC_GPIO_NUM     23
  
  #define Y9_GPIO_NUM       19
  #define Y8_GPIO_NUM       36
  #define Y7_GPIO_NUM       18
  #define Y6_GPIO_NUM       39
  #define Y5_GPIO_NUM        5
  #define Y4_GPIO_NUM       34
  #define Y3_GPIO_NUM       35
  #define Y2_GPIO_NUM       32
  #define VSYNC_GPIO_NUM    25
  #define HREF_GPIO_NUM     26
  #define PCLK_GPIO_NUM     21

#else
  #error "Camera model not selected"
#endif
//instatiation of heandler constants, neede for the communication between server and client
static const char* _STREAM_CONTENT_TYPE = "multipart/x-mixed-replace;boundary=" PART_BOUNDARY;
static const char* _STREAM_BOUNDARY = "\r\n--" PART_BOUNDARY "\r\n";
static const char* _STREAM_PART = "Content-Type: image/jpeg\r\nContent-Length: %u\r\n\r\n";

httpd_handle_t camera_httpd = NULL;
httpd_handle_t stream_httpd = NULL;

//here the HTML code of the webserver starts, if you want to change something for the webserve 
//you can make it here. I personally copy paste it to VSCode with HTML addon to see the change in realtime
//don't forget to copy paste it back here afterwards ;D
static const char PROGMEM INDEX_HTML[] = R"rawliteral(
<html>
  <head>
    <title>delta3Robotics</title>
    <meta name="viewport" content="width=device-width, initial-scale=1">
    <style>
      :root{
        --back: #858080;
        --backLog: darkgrey;
        --activeData: purple;
        --font: black;
        --BtnBackground: gray;
        --btnBorder: black;
        --BtnBackgroundDis: rgb(87, 86, 86);
        --BtnLegAct: purple; 
      }
      body { 
        font-family: Arial; 
        text-align: center; 
        background-color: var(--back);
        position: absolute;
        margin: 0px;
        overflow: hidden;
        top: 0px;
        bottom: 0px;
        width: 100%;
        height: 100%;
    }
      table { 
        margin-left: 0%; 
        margin-right: 0px; 
    }

      td { 
        padding:  1px; 
        align-items:"center";
    }

    .log {
        color: var(--activeData);
        font-size: 13px;
        text-align: left;
        margin-left: 5px;
    }
    .var {
        color: var(--font);
        font-size: 13px;
        text-align: left;
        margin-left: 5px;
    }

    .height{
      color: var(--activeData);
      font-size: 17px;
      text-align: left;
      margin-left: 5px;
    }

      .button {
        color: var(--font);
        background-color: var(--BtnBackground);
        border: solid;
        border-color: var(--btnBorder);
        border-radius: 100%;
        width: 60px;
        height: 60px;
        text-align: center;
        text-decoration: none;
        display: inline-block;
        font-size: 18px;
        cursor: pointer;
        -webkit-touch-callout: none;
        -webkit-user-select: none;
        -khtml-user-select: none;
        -moz-user-select: none;
        -ms-user-select: none;
        user-select: none;
        -webkit-tap-highlight-color: rgba(0,0,0,0);
      }
      .button:active {
        border-color: var(--activeData);
      }

      .buttonDisabled {
        color: black;
        background-color: var(--back);
        border: none;
        border-radius: 100%;
        width: 60px;
        height: 60px;
        text-align: center;
        text-decoration: none;
        display: inline-block;
        font-size: 18px;
        cursor: pointer;
        -webkit-touch-callout: none;
        -webkit-user-select: none;
        -khtml-user-select: none;
        -moz-user-select: none;
        -ms-user-select: none;
        user-select: none;
        -webkit-tap-highlight-color: rgba(0,0,0,0);
      }
      .buttondisabled:active {
        background-color: var(--back);
      }

      .buttonLeg {
        color: var(--font);
        background-color: var(--BtnLegAct);
        border: solid;
        border-radius: 100%;
        width: 40px;
        height: 40px;
        text-align: center;
        text-decoration: none;
        display: inline-block;
        font-size: 18px;
        cursor: pointer;
        -webkit-touch-callout: none;
        -webkit-user-select: none;
        -khtml-user-select: none;
        -moz-user-select: none;
        -ms-user-select: none;
        user-select: none;
        -webkit-tap-highlight-color: rgba(0,0,0,0);
      }
      .buttonLeg:active {
        background-color: var(--activeData);
      }

    .containerA {
        display: grid;
        width: 100%;
        height: 100%;
        grid-template-columns: [col0] 20% [col1] 60% [col2] 20% [col3];
        grid-template-rows: [row0] 10% [row1] 20% [row2] 35% [row3] 30% [row4]; 
        column-gap: 5px;
        row-gap: 5px;   
        justify-self: start;
        align-self: start;
        justify-items: center;
        align-items: center;
    }

    .item-info1 {
        padding-left: 10px;
        grid-column-start: col0;
        grid-column-end: col1;
        grid-row-start: row0;
        grid-row-end: row2;
        justify-self: stretch;
        align-self: stretch;
        line-height: 40%;
        justify-content: left;
    }

    .item-info2 {
        grid-column-start: col0;
        grid-column-end: col1;
        grid-row-start: row2;
        grid-row-end: row3;
        align-self: stretch;
        justify-self: stretch;
        line-height: 40%;
        align-items: center;
        justify-items: center;
    }  
    
    .item-bt1 {
        grid-column-start: col0;
        grid-column-end: col1;
        grid-row-start: row3;
        grid-row-end: row4;
    }

    .item-heading {
        grid-column-start: col1;
        grid-column-end: col2;
        grid-row-start: row0;
        grid-row-end: row1;
        justify-self: center;
        align-self: center;
    }

    .item-stream {
        grid-column-start: col1;
        grid-column-end: col2;
        grid-row-start: row1;
        grid-row-end: row4;
        justify-self: stretch;
        align-self: stretch;
        
    }
    .item-bt3 {
        grid-column-start: col2;
        grid-column-end: col3;
        grid-row-start: row0;
        grid-row-end: row2;

    }
    .item-info3 {
        grid-column-start: col2;
        grid-column-end: col3;
        grid-row-start: row2;
        grid-row-end: row3;

    }
    .item-bt2 {
        grid-column-start: col2;
        grid-column-end: col3;
        grid-row-start: row3;
        grid-row-end: row4;
    }
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
void loop() {
  //Start and stop the LED
  if(lightOn==true){
    digitalWrite(LED_BUILTIN, HIGH);
  } else{
    digitalWrite(LED_BUILTIN, LOW);
  }

//here the movment skript starts
//arming = activate
  if(arm==true){
    //select height
    if(height.equals("1000") && ch_1==1500 && ch_2==1500 && wave==false){
      stepLength = stepLengthLow; 
      stepLift = stepLiftLow;
      a1=a3=40+map(ch_3, 1000, 2000, -25, 25);
      a5=a7=40;
      a9=a11=40-map(ch_3, 1000, 2000, -25, 25);
    }
      if(height.equals("1500") && ch_1==1500 && ch_2==1500 && wave==false){
      stepLength = stepLengthMid;
      stepLift = stepLiftMid;
      a1=a3=60+map(ch_3, 1000, 2000, -25, 25);
      a5=a7=60;
      a9=a11=60-map(ch_3, 1000, 2000, -25, 25);
    }
      if(height.equals("2000") && ch_1==1500 && ch_2==1500 && wave==false){
      stepLength = stepLengthHigh;
      stepLift = stepLiftHigh;
      a1=a3=90;
      if(a11<=90){
        a5=a7=90-(0.5*map(ch_3, 1000, 2000, -40, 40));
        a9=a11=90-(0.5*map(ch_3, 1000, 2000, -40, 40));
      }
    }
//stand if not actuated
    if(ch_1==1500 && ch_2!=2000 && ch_2!=1000 && wave==false){
      v=vFast;
      a0=map(ch_2, 1000, 2000, -85, 85);
      a2=-map(ch_2, 1000, 2000, -85, 85);
      a4=map(ch_2, 1000, 2000, -85, 85);
      a6=-map(ch_2, 1000, 2000, -85, 85);
      a8=map(ch_2, 1000, 2000, -85, 85);
      a10=-map(ch_2, 1000, 2000, -85, 85);
      step=0;

    }
//wave
    if(wave==true){
      a3=-85;
      if(a2r==stepLength && a3r==-85){
        a2=0;
      }
      if(a2r==0 && a3r==-85){
        a2=stepLength;
      }
    }
//Walk forward
    if(ch_1>=1600){
      ch_2=1500;
      ch_3=1500;
      if(a0r==0 && a2r==0 && a4r==0 && a6r==0 && a8r==0 && a10r==0 && step==0){
        liftLeg(1);
        liftLeg(7);
        liftLeg(9);
        a0=stepLength;
        a2=0; 
        a4=0; 
        a6=stepLength; 
        a8=stepLength; 
        a10=0; 
        step=1;
      }
      if(a0r==stepLength && a2r==0 && a4r==0 && a6r==stepLength && a8r==stepLength && a10r==0){
        lowerLeg(1);
        lowerLeg(7);
        lowerLeg(9);
        v=vSlow;
        a0=0;
        a2=-stepLength; 
        a4=-stepLength; 
        a6=0; 
        a8=0; 
        a10=-stepLength; 
        step=2;
      }
      if(a0r==0 && a2r==-stepLength && a4r==-stepLength && a6r==0 && a8r==0 && a10r==-stepLength){
        v=vFast;
        liftLeg(3);
        liftLeg(5);
        liftLeg(11);
        a0=0;
        a2=stepLength; 
        a4=stepLength; 
        a6=0; 
        a8=0; 
        a10=stepLength; 
        step=3;
      }
      if(a0r==0 && a2r==stepLength && a4r==stepLength && a6r==0 && a8r==0 && a10r==stepLength){
        lowerLeg(3);
        lowerLeg(5);
        lowerLeg(11);
        v=vSlow;
        a0=-stepLength;
        a2=0; 
        a4=0; 
        a6=-stepLength; 
        a8=-stepLength; 
        a10=0; 
        step=4;
      }
      if(a0r==-stepLength && a2r==0 && a4r==0 && a6r==-stepLength && a8r==-stepLength && a10r==0){
        v=vFast;
        liftLeg(1);
        liftLeg(7);
        liftLeg(9);
        a0=stepLength;
        a2=0; 
        a4=0; 
        a6=stepLength; 
        a8=stepLength; 
        a10=0; 
        step=5;
      }
    }
//Walk backwards
    if(ch_1<=1400){
      ch_2=1500;
      ch_3=1500;
      if(a0r==0 && a2r==0 && a4r==0 && a6r==0 && a8r==0 && a10r==0 && step==0){
        liftLeg(1);
        liftLeg(7);
        liftLeg(9);
        a0=-stepLength;
        a2=0; 
        a4=0; 
        a6=-stepLength; 
        a8=-stepLength; 
        a10=0; 
        step=1;
      }
      if(a0r==-stepLength && a2r==0 && a4r==0 && a6r==-stepLength && a8r==-stepLength && a10r==0){
        lowerLeg(1);
        lowerLeg(7);
        lowerLeg(9);
        v=vSlow;
        a0=0;
        a2=stepLength; 
        a4=stepLength; 
        a6=0; 
        a8=0; 
        a10=stepLength; 
        step=2;
      }
      if(a0r==0 && a2r==stepLength && a4r==stepLength && a6r==0 && a8r==0 && a10r==stepLength){
        v=vFast;
        liftLeg(3);
        liftLeg(5);
        liftLeg(11);
        a0=0;
        a2=-stepLength; 
        a4=-stepLength; 
        a6=0; 
        a8=0; 
        a10=-stepLength; 
        step=3;
      }
      if(a0r==0 && a2r==-stepLength && a4r==-stepLength && a6r==0 && a8r==0 && a10r==-stepLength){
        lowerLeg(3);
        lowerLeg(5);
        lowerLeg(11);
        v=vSlow;
        a0=stepLength;
        a2=0; 
        a4=0; 
        a6=stepLength; 
        a8=stepLength; 
        a10=0; 
        step=4;
      }
      if(a0r==stepLength && a2r==0 && a4r==0 && a6r==stepLength && a8r==stepLength && a10r==0){
        v=vFast;
        liftLeg(1);
        liftLeg(7);
        liftLeg(9);
        a0=-stepLength;
        a2=0; 
        a4=0; 
        a6=-stepLength; 
        a8=-stepLength; 
        a10=0; 
        step=5;
      }
    }

//Turn Left
    if(ch_2<=1400){
      if(a0r==0 && a2r==0 && a4r==0 && a6r==0 && a8r==0 && a10r==0 && step==0){
        a0=-stepLength;
        a2=stepLength; 
        a4=-stepLength; 
        a6=stepLength; 
        a8=-stepLength;
        a10=stepLength;
        step=1;
      }
      if(a0r==-stepLength && a2r==stepLength && a4r==-stepLength && a6r==stepLength && a8r==-stepLength && a10r==stepLength){
        liftLeg(1);
        liftLeg(7);
        liftLeg(9);
        a0=0;
        a2=stepLength; 
        a4=-stepLength; 
        a6=0; 
        a8=0;
        a10=stepLength;
        step=2;
      }
      if(a0r==0 && a2r==stepLength && a4r==-stepLength && a6r==0 && a8r==0 && a10r==stepLength){
        lowerLeg(1);
        lowerLeg(7);
        lowerLeg(9);
        step=3;
      }
      if(a0r==0 && a2r==stepLength && a4r==-stepLength && a6r==0 && a8r==0 && a10r==stepLength && step==3){
        liftLeg(3);
        liftLeg(5);
        liftLeg(11);
        a0=0;
        a2=0; 
        a4=0; 
        a6=0; 
        a8=0;
        a10=0;
        step=4;
      }
      if(a0r==0 && a2r==0 && a4r==0 && a6r==0 && a8r==0 && a10r==0 && step==4){
        lowerLeg(3);
        lowerLeg(5);
        lowerLeg(11);
        step=0;
      }
    }
//Turn Right
    if(ch_2>=1600){
      if(a0r==0 && a2r==0 && a4r==0 && a6r==0 && a8r==0 && a10r==0 && step==0){
        a0=stepLength;
        a2=-stepLength; 
        a4=stepLength; 
        a6=-stepLength; 
        a8=stepLength;
        a10=-stepLength;
        step=1;
      }
      if(a0r==stepLength && a2r==-stepLength && a4r==stepLength && a6r==-stepLength && a8r==stepLength && a10r==-stepLength){
        liftLeg(1);
        liftLeg(7);
        liftLeg(9);
        a0=0;
        a2=-stepLength; 
        a4=stepLength; 
        a6=0; 
        a8=0;
        a10=-stepLength;
        step=2;
      }
      if(a0r==0 && a2r==-stepLength && a4r==stepLength && a6r==0 && a8r==0 && a10r==-stepLength){
        lowerLeg(1);
        lowerLeg(7);
        lowerLeg(9);
        step=3;
      }
      if(a0r==0 && a2r==-stepLength && a4r==stepLength && a6r==0 && a8r==0 && a10r==-stepLength && step==3){
        liftLeg(3);
        liftLeg(5);
        liftLeg(11);
        a0=0;
        a2=0; 
        a4=0; 
        a6=0; 
        a8=0;
        a10=0;
        step=4;
      }
      if(a0r==0 && a2r==0 && a4r==0 && a6r==0 && a8r==0 && a10r==0 && step==4){
        lowerLeg(3);
        lowerLeg(5);
        lowerLeg(11);
        step=0;
      }
    }
  }
//Pose for disarmed
  else{
  a0=a2=a4=a6=a8=a10=0;
  a1=a3=a5=a7=a9=a11=legIdle;
  }

  //pack all the data into one very long char to send it back to the client
  feedBackToClient= light + "," + armed + "," + height + "," + mode + "," + footFL + "," + footFR + "," + footBL + "," + footBR + "," + temp + "," + rotX + "," + rotY + "," + rotZ + "," + distFr + "," + distFrL + "," + distFrL + "," + distBott;
  feedBackToClient.toCharArray (dataToClient, 70);
  //Serial.println (dataToClient);


//Simple ramped controller to set the speed of the servos, control speed via delay (int v) and eps is used to implement deadband and avoid jittering 
if(a0r<=a0-eps){
  setServo(0,a0r+90+korr+comp0); 
  a0r = a0r+t;
}
else if(a0r>=a0+eps){
  setServo(0,a0r+90+korr+comp0);
  a0r = a0r-t; 
}
else{
  a0r=a0;
  setServo(0,a0r+90+korr+comp0);
}

if(a1r<=a1-eps){
  setServo(1,180-a1r-90+comp1); 
  a1r = a1r+t;
}
else if(a1r>=a1+eps){
  setServo(1,180-a1r-90+comp1); 
  a1r = a1r-t;
}
else{
  a1r=a1;
  setServo(1,180-a1r-90+comp1);
}

if(a2r<=a2-eps){
  setServo(2,90-a2r-korr+comp2); 
  a2r = a2r+t;
}
else if(a2r>=a2+eps){
  setServo(2,90-a2r-korr+comp2);  
  a2r = a2r-t;
}
else{
  a2r=a2;
  setServo(2,90-a2r-korr+comp2); 
}

if(a3r<=a3-eps){
  setServo(3,a3r+90+comp3); 
  a3r = a3r+t;
}
else if(a3r>=a3+eps){
  setServo(3,a3r+90+comp3);  
  a3r = a3r-t;
}
else{
  a3r=a3;
  setServo(3,a3r+90+comp3); 
}
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

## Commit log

2025-01-05 Initial copy of SIXPack download
    [Body.step, Body.stl, CapLeft.step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]
2025-01-05 Add FTDI driver install to readme, however it hasn't worked yet on mac Sequoia
2025-01-11 Add servo calibration details
2025-01-12 Reset compoensation to zero
    [SIXpackAccesPoint.ino]
2025-01-12 Start thinking about how to select servo movement
2025-01-15 Add mover to servo to own the selection of the next position
